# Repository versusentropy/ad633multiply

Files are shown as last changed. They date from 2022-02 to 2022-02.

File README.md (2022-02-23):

# eurorack AD633 mulitply

## v2 

minor bugfixes - should workk exactly like my manually fixed version - but I have not ordered these exact gerbers. Please report, if you do.

### 4 to 3 matrix mixer with gain 2

### 3 outputs to AD633 (X * Y) / 10 + Z

### output gain 0..1.5

### 2 DC coupled outputs
one with fixed gain

### 2 AC coupled outputs

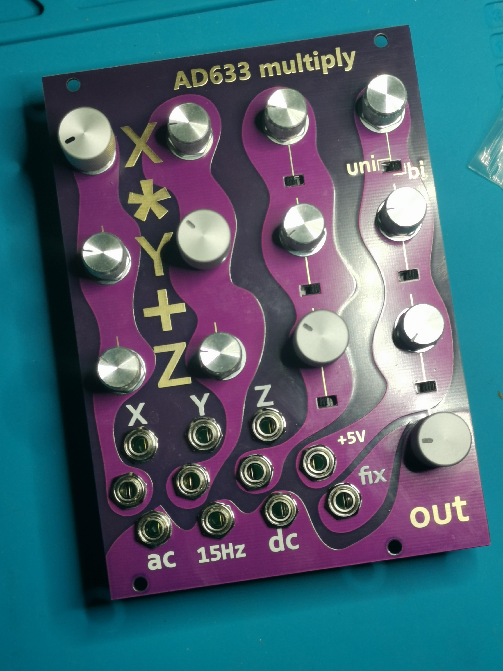
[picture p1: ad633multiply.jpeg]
pcb


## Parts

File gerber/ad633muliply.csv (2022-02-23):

Comment | Designator | Footprint | LCSC
22uF | C1,C2,C30 | Capacitor_SMD:C_0805_2012Metric | C45783
68pF | C13,C14,C15,C16,C17,C18,C21,C22,C23,C24,C26,C28 | Capacitor_SMD:C_0402_1005Metric | C14441
100n 50V X7R | C3,C4,C5,C6,C7,C8,C9,C10,C11,C12,C19,C20,C25,C29 | Capacitor_SMD:C_0402_1005Metric | C307331
LM4040C50FTA | D1 | Package_TO_SOT_SMD:SOT-23 | C202168
16V 150mA 0805 PTC Resettable Fuses ROHS | FB1,FB2 | Fuse:Fuse_0805_2012Metric | C30198
22k | R1,R76 | Resistor_SMD:R_0603_1608Metric | C126297
1k | R2,R5,R35,R36,R40,R42,R78,R79 | Resistor_SMD:R_0603_1608Metric | C21190
200k | R21,R22,R23,R33,R34,R43 | Resistor_SMD:R_0603_1608Metric | C319781
10k | R3 | Resistor_SMD:R_0402_1005Metric | C98838
36k5 | R4,R74 | Resistor_SMD:R_0603_1608Metric | C51261
100k | R6,R7,R8,R9,R10,R11,R12,R13,R14,R15,R16,R17,R18,R19,R20,R30,R31,R32,R37,R38,R39,R57,R59,R60,R63,R64 | Resistor_SMD:R_0402_1005Metric | C319963
TL074 | U1,U9,U10,U11 | Package_SO:TSSOP-14_4.4x5mm_P0.65mm | C96507
Xout | J1 | kicad_jacks:Jack_3.5mm_QingPu_WQP-PJ398SM_Vertical_CircularHolesSMALL
ac_15_out | J2 | kicad_jacks:Jack_3.5mm_QingPu_WQP-PJ398SM_Vertical_CircularHolesSMALL
Ain | J20 | kicad_jacks:Jack_3.5mm_QingPu_WQP-PJ398SM_Vertical_CircularHolesSMALL
Cin | J21 | kicad_jacks:Jack_3.5mm_QingPu_WQP-PJ398SM_Vertical_CircularHolesSMALL
ac_159_out | J22 | kicad_jacks:Jack_3.5mm_QingPu_WQP-PJ398SM_Vertical_CircularHolesSMALL
Yout | J3 | kicad_jacks:Jack_3.5mm_QingPu_WQP-PJ398SM_Vertical_CircularHolesSMALL
Din | J33 | kicad_jacks:Jack_3.5mm_QingPu_WQP-PJ398SM_Vertical_CircularHolesSMALL
out | J34 | kicad_jacks:Jack_3.5mm_QingPu_WQP-PJ398SM_Vertical_CircularHolesSMALL
outAtt | J37 | kicad_jacks:Jack_3.5mm_QingPu_WQP-PJ398SM_Vertical_CircularHolesSMALL
Bin | J38 | kicad_jacks:Jack_3.5mm_QingPu_WQP-PJ398SM_Vertical_CircularHolesSMALL
Zout | J4 | kicad_jacks:Jack_3.5mm_QingPu_WQP-PJ398SM_Vertical_CircularHolesSMALL
25kB to 100kB | RV6 | myKicadLib:RD901F-ALPHA-POT-T18
100kB | RV1,RV2,RV3,RV4,RV5,RV7,RV8,RV9,RV10,RV11,RV12,RV13 | myKicadLib:RD901F-ALPHA-POT-T18
AS1D-2M-10-Z | SW1,SW2,SW3,SW4,SW5,SW6 | myKicadLib:AS1D-2M-10-Z
AD633 | U12 | Package_DIP:DIP-8_W7.62mm_Socket
POWER | J6 | myKicadLib:eurorac_power
AC outs unity att | J5 | Connector_PinHeader_2.54mm:PinHeader_1x03_P2.54mm_Vertical
?k | R41 | Resistor_THT:R_Axial_DIN0207_L6.3mm_D2.5mm_P10.16mm_Horizontal | optional remove R@RC
?nF | C27 | Capacitor_THT:CP_Radial_D6.3mm_P2.50mm | optional remove C@RC

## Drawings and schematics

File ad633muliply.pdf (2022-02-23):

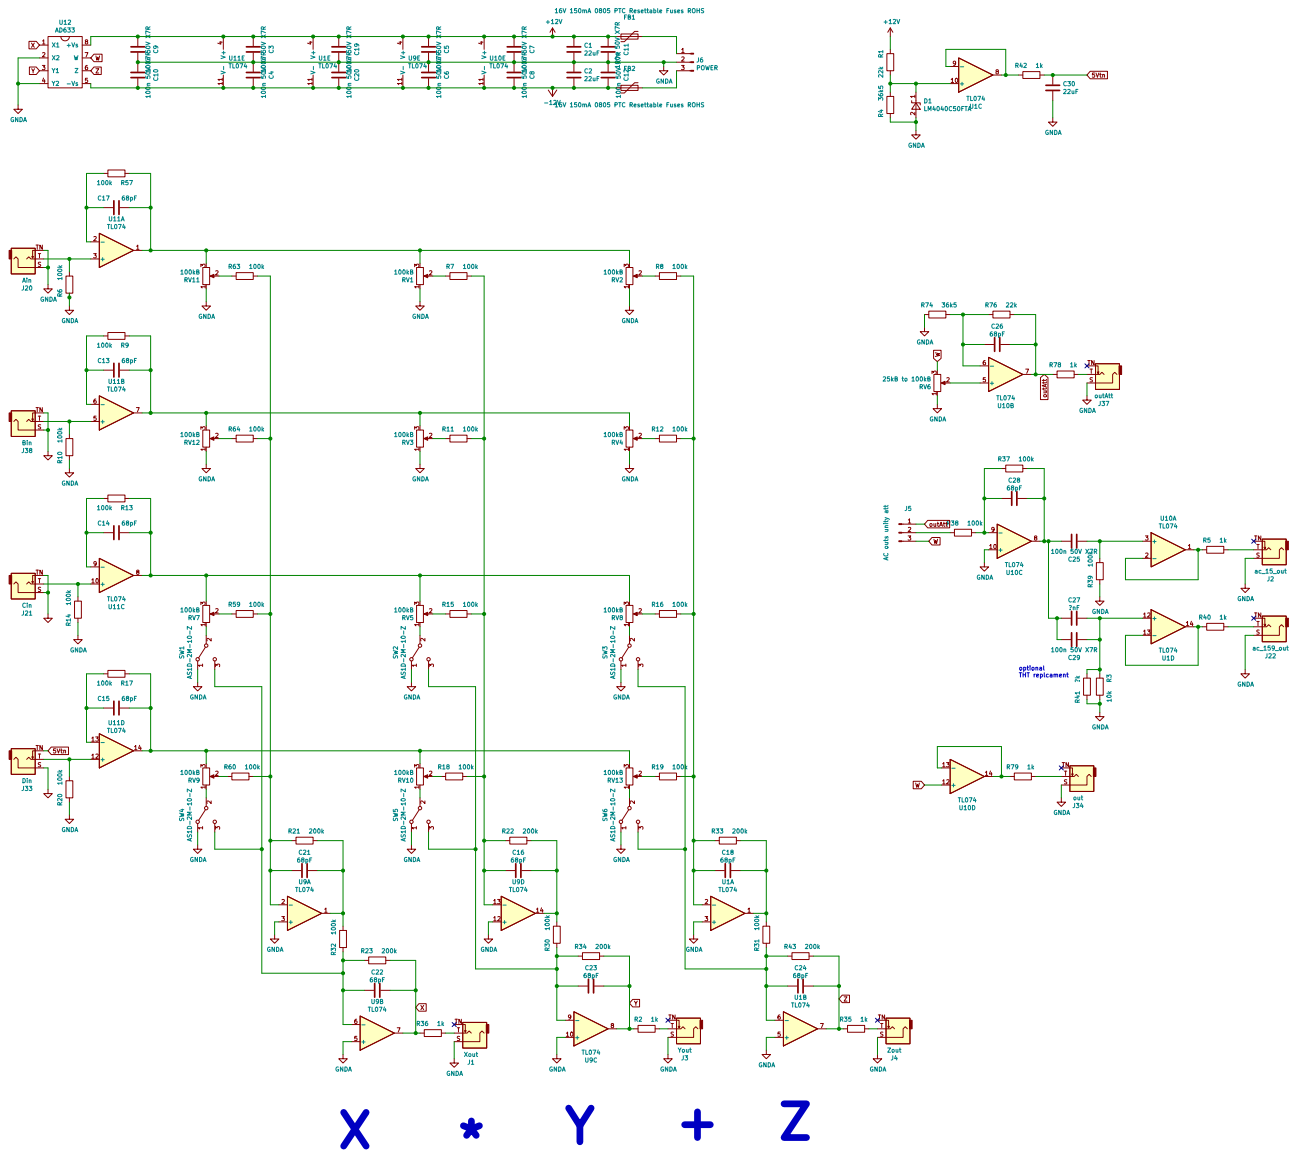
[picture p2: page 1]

16V 150mA 0805 PTC Resettable Fuses ROHS

16V 150mA 0805 PTC Resettable Fuses ROHS GNDA

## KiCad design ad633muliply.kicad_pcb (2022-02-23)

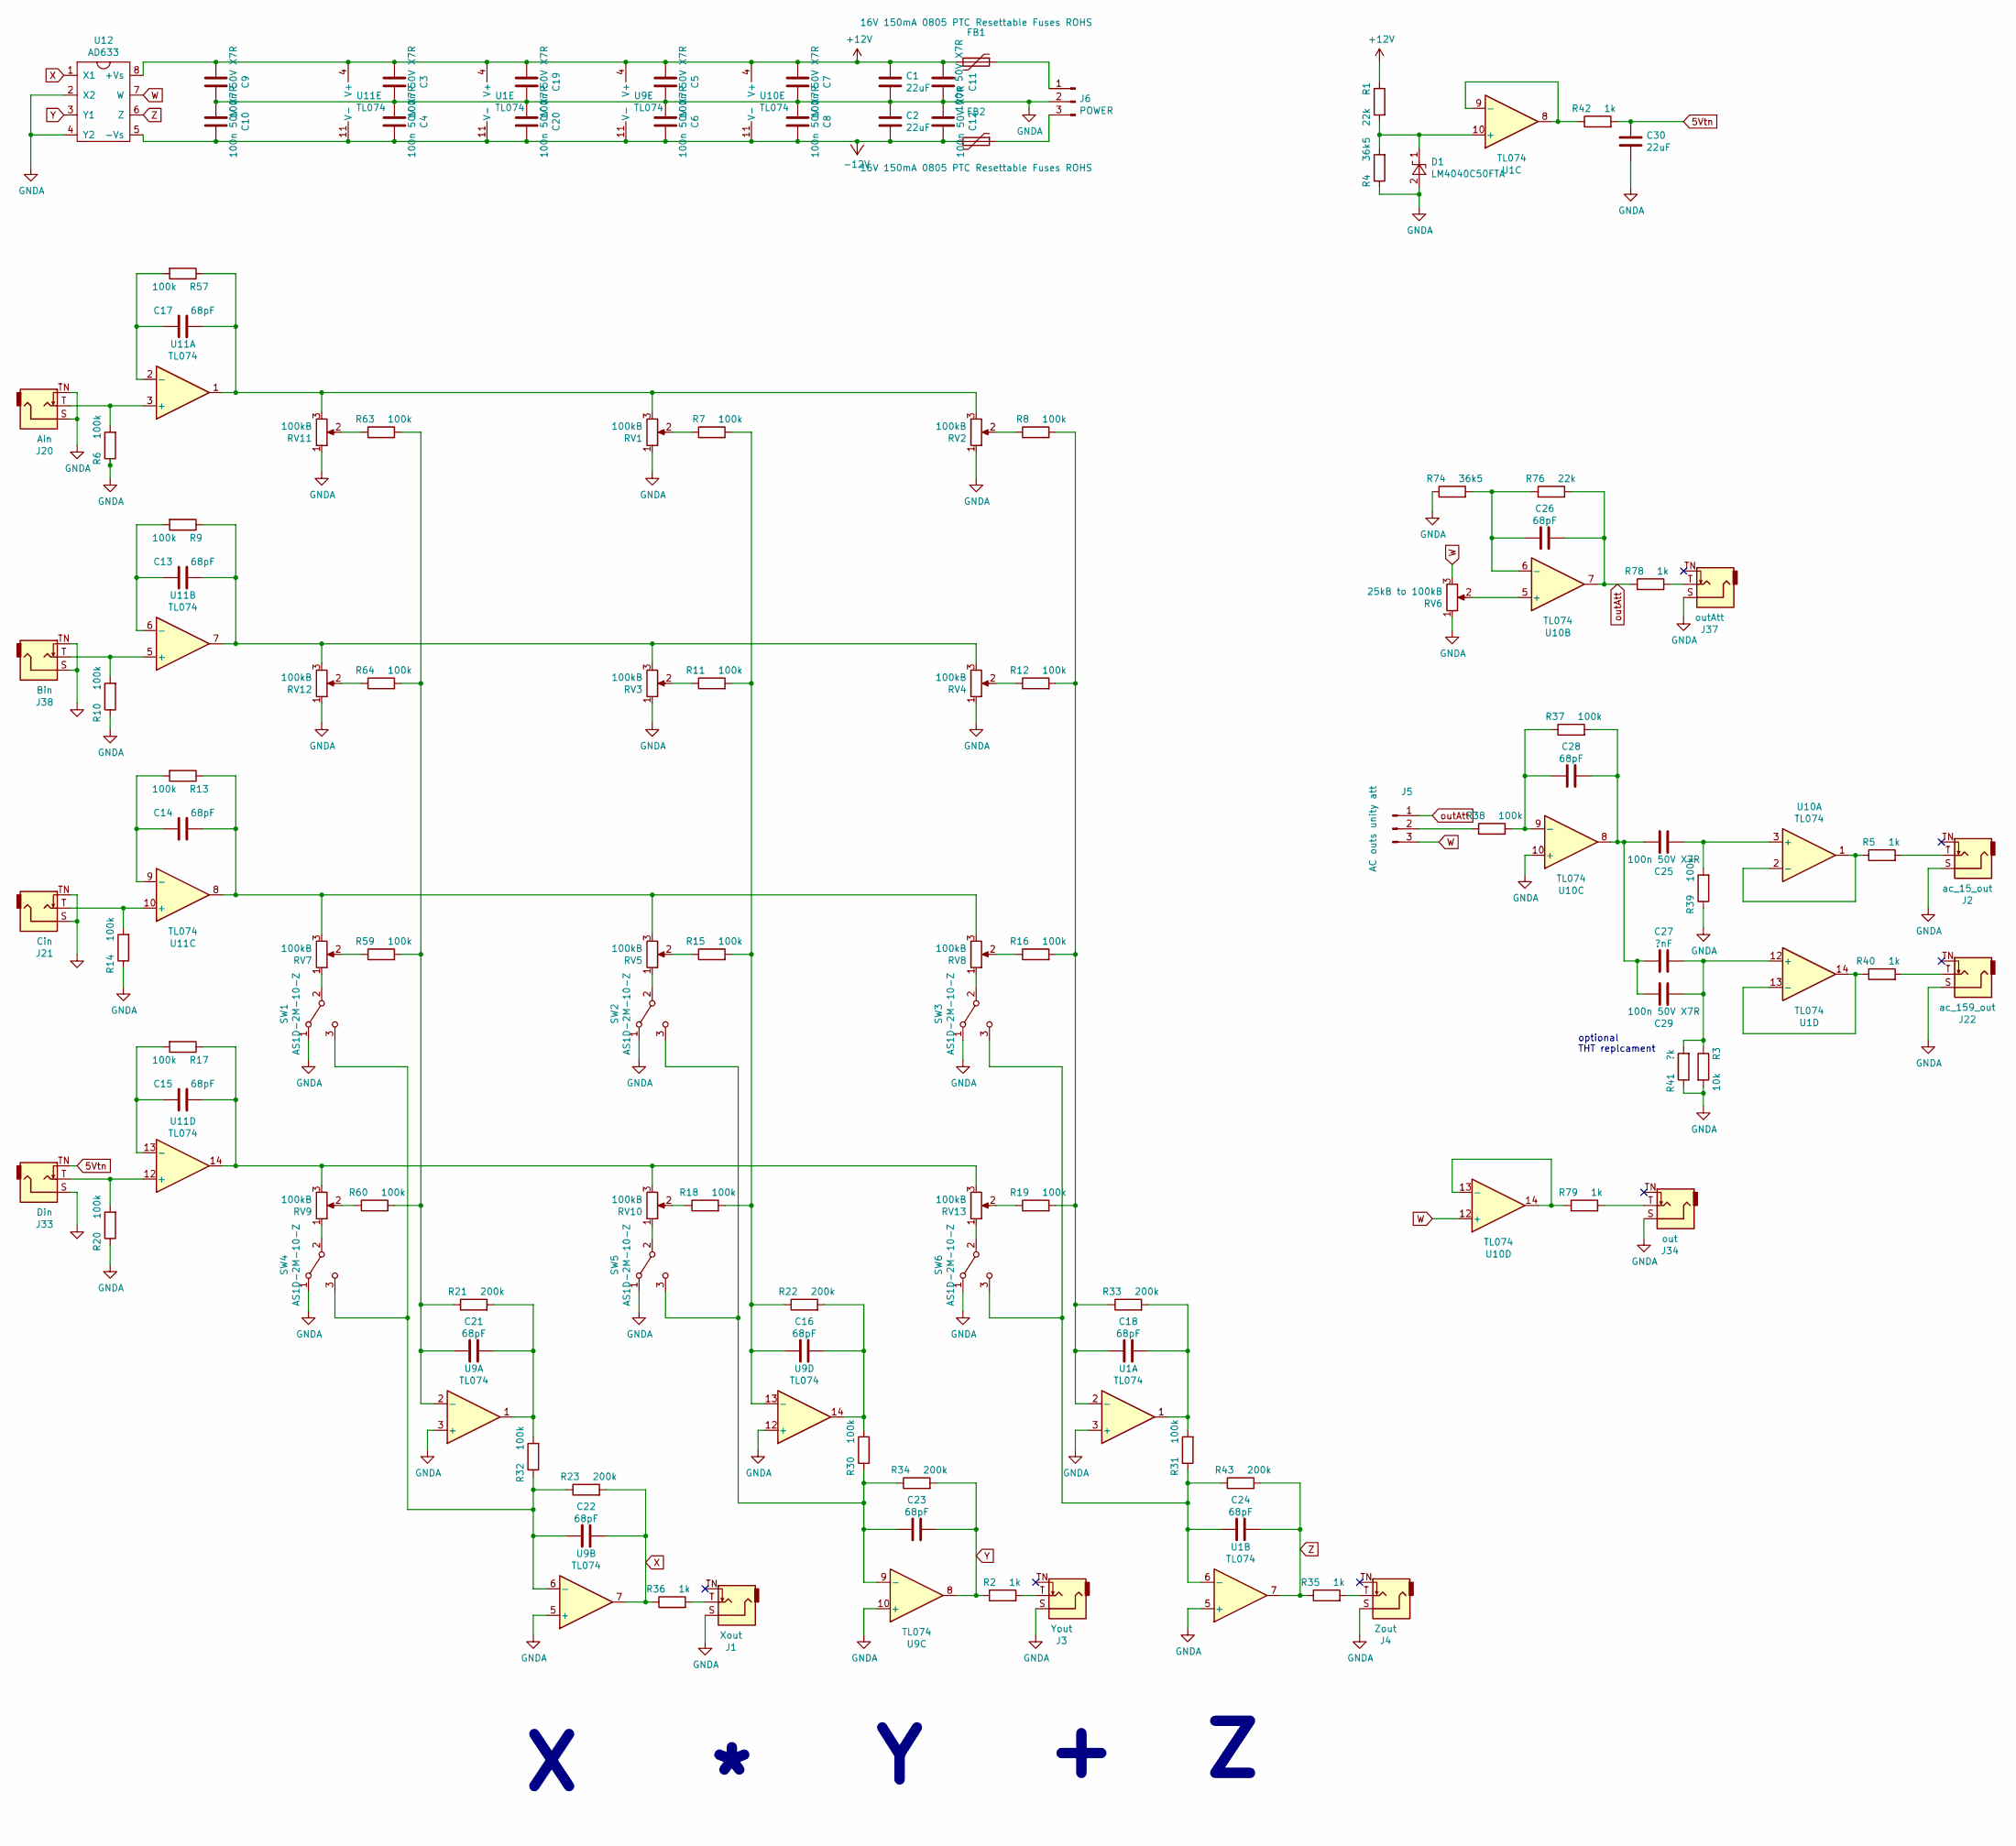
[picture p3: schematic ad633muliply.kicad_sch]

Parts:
C1, C2, C30: 22uF; C_0805_2012Metric; LCSC C45783
C3, C4, C5, C6, C7, C8, C9, C10, C11, C12, C19, C20, C25, C29: 100n 50V X7R; C_0402_1005Metric; LCSC C307331
C13, C14, C15, C16, C17, C18, C21, C22, C23, C24, C26, C28: 68pF; C_0402_1005Metric; LCSC C14441
C27: ?nF; CP_Radial_D6.3mm_P2.50mm
D1: LM4040C50FTA; SOT-23; LCSC C202168
FB1, FB2: 16V 150mA 0805 PTC Resettable Fuses ROHS; Fuse_0805_2012Metric; LCSC C30198
J1: Xout; Jack_3.5mm_QingPu_WQP-PJ398SM_Vertical_CircularHolesSMALL
J2: ac_15_out; Jack_3.5mm_QingPu_WQP-PJ398SM_Vertical_CircularHolesSMALL
J3: Yout; Jack_3.5mm_QingPu_WQP-PJ398SM_Vertical_CircularHolesSMALL
J4: Zout; Jack_3.5mm_QingPu_WQP-PJ398SM_Vertical_CircularHolesSMALL
J5: AC outs unity att; PinHeader_1x03_P2.54mm_Vertical
J6: POWER; eurorac_power
J20: Ain; Jack_3.5mm_QingPu_WQP-PJ398SM_Vertical_CircularHolesSMALL
J21: Cin; Jack_3.5mm_QingPu_WQP-PJ398SM_Vertical_CircularHolesSMALL
J22: ac_159_out; Jack_3.5mm_QingPu_WQP-PJ398SM_Vertical_CircularHolesSMALL
J33: Din; Jack_3.5mm_QingPu_WQP-PJ398SM_Vertical_CircularHolesSMALL
J34: out; Jack_3.5mm_QingPu_WQP-PJ398SM_Vertical_CircularHolesSMALL
J37: outAtt; Jack_3.5mm_QingPu_WQP-PJ398SM_Vertical_CircularHolesSMALL
J38: Bin; Jack_3.5mm_QingPu_WQP-PJ398SM_Vertical_CircularHolesSMALL
R1, R76: 22k; R_0603_1608Metric; LCSC C126297
R2, R5, R35, R36, R40, R42, R78, R79: 1k; R_0603_1608Metric; LCSC C21190
R3: 10k; R_0402_1005Metric; LCSC C98838
R4, R74: 36k5; R_0603_1608Metric; LCSC C51261
R6, R7, R8, R9, R10, R11, R12, R13, R14, R15, R16, R17, R18, R19, R20, R30, R31, R32, R37, R38, R39, R57, R59, R60, R63, R64: 100k; R_0402_1005Metric; LCSC C319963
R21, R22, R23, R33, R34, R43: 200k; R_0603_1608Metric; LCSC C319781
R41: ?k; R_Axial_DIN0207_L6.3mm_D2.5mm_P10.16mm_Horizontal
RV1, RV2, RV3, RV4, RV5, RV7, RV8, RV9, RV10, RV11, RV12, RV13: 100kB; RD901F-ALPHA-POT-T18
RV6: 25kB to 100kB; RD901F-ALPHA-POT-T18
SW1, SW2, SW3, SW4, SW5, SW6: AS1D-2M-10-Z; Mouser 229-AS1D-2M-10-Z
U1, U9, U10, U11: TL074; TSSOP-14_4.4x5mm_P0.65mm; LCSC C96507
U12: AD633; DIP-8_W7.62mm_Socket; Mouser 584-AD633ANZ

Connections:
5Vtn: C30.1, J33.TN, R42.2
+12V: C1.1, C3.2, C5.2, C7.2, C9.2, C11.2, C19.2, FB1.2, R1.1, U1.4 (V+), U9.4 (V+), U10.4 (V+), U11.4 (V+), U12.8 (+Vs)
-12V: C2.2, C4.1, C6.1, C8.1, C10.1, C12.1, C20.1, FB2.2, U1.11 (V-), U9.11 (V-), U10.11 (V-), U11.11 (V-), U12.5 (-Vs)
GNDA: C1.2, C2.1, C3.1, C4.2, C5.1, C6.2, C7.1, C8.2, C9.1, C10.2, C11.1, C12.2, C19.1, C20.2, C30.2, D1.2 (A), J1.S, J2.S, J3.S, J4.S, J6.2, J20.S, J20.TN, J21.S, J21.TN, J22.S, J33.S, J34.S, J37.S, J38.S, J38.TN, R3.2, R4.1, R6.1, R10.1, R14.1, R20.1, R39.1, R41.1, R74.1, RV1.1, RV2.1, RV3.1, RV4.1, RV6.1, RV11.1, RV12.1, SW1.1 (A), SW2.1 (A), SW3.1 (A), SW4.1 (A), SW5.1 (A), SW6.1 (A), U1.3 (+), U1.5 (+), U9.3 (+), U9.5 (+), U9.10 (+), U9.12 (+), U10.10 (+), U12.2 (X2), U12.4 (Y2)
unnamed: C13.1, R9.1, RV3.3, RV4.3, RV12.3, U11.7
unnamed: C13.2, R9.2, U11.6 (-)
unnamed: C14.1, R13.1, RV5.3, RV7.3, RV8.3, U11.8
unnamed: C14.2, R13.2, U11.9 (-)
unnamed: C15.1, R17.1, RV9.3, RV10.3, RV13.3, U11.14
unnamed: C15.2, R17.2, U11.13 (-)
unnamed: C16.1, R22.2, R30.2, U9.14
unnamed: C16.2, R7.2, R11.2, R15.2, R18.2, R22.1, U9.13 (-)
unnamed: C17.1, R57.1, RV1.3, RV2.3, RV11.3, U11.1
unnamed: C17.2, R57.2, U11.2 (-)
unnamed: C18.1, R31.2, R33.2, U1.1
unnamed: C18.2, R8.2, R12.2, R16.2, R19.2, R33.1, U1.2 (-)
unnamed: C21.1, R21.2, R32.2, U9.1
unnamed: C21.2, R21.1, R59.2, R60.2, R63.2, R64.2, U9.2 (-)
unnamed: C23.2, R30.1, R34.1, SW2.3 (C), SW5.3 (C), U9.9 (-)
unnamed: C25.1, C27.2, C28.1, C29.1, R37.2, U10.8
unnamed: C25.2, R39.2, U10.3 (+)
unnamed: C26.2, R74.2, R76.1, U10.6 (-)
unnamed: C27.1, C29.2, R3.1, R41.2, U1.12 (+)
unnamed: C28.2, R37.1, R38.2, U10.9 (-)
unnamed: D1.1 (K), R1.2, R4.2, U1.10 (+)
unnamed: FB1.1, J6.1
unnamed: FB2.1, J6.3
unnamed: J1.T, R36.2
unnamed: J2.T, R5.2
unnamed: J3.T, R2.2
unnamed: J4.T, R35.2
unnamed: J5.2, R38.1
unnamed: J20.T, R6.2, U11.3 (+)
unnamed: J21.T, R14.2, U11.10 (+)
unnamed: J22.T, R40.2
unnamed: J33.T, R20.2, U11.12 (+)
unnamed: J34.T, R79.2
unnamed: J37.T, R78.2
unnamed: J38.T, R10.2, U11.5 (+)
unnamed: R5.1, U10.1, U10.2 (-)
unnamed: R7.1, RV1.2
unnamed: R8.1, RV2.2
unnamed: R11.1, RV3.2
unnamed: R12.1, RV4.2
unnamed: R15.1, RV5.2
unnamed: R16.1, RV8.2
unnamed: R18.1, RV10.2
unnamed: R19.1, RV13.2
unnamed: R40.1, U1.13 (-), U1.14
unnamed: R42.1, U1.8, U1.9 (-)
unnamed: R59.1, RV7.2
unnamed: R60.1, RV9.2
unnamed: R63.1, RV11.2
unnamed: R64.1, RV12.2
unnamed: R79.1, U10.13 (-), U10.14
unnamed: RV5.1, SW2.2 (B)
unnamed: RV7.1, SW1.2 (B)
unnamed: RV8.1, SW3.2 (B)
unnamed: RV9.1, SW4.2 (B)
unnamed: RV10.1, SW5.2 (B)
unnamed: RV13.1, SW6.2 (B)
unnamed: C22.2, R23.1, R32.1, SW1.3 (C), SW4.3 (C), U9.6 (-)
unnamed: C24.2, R31.1, R43.1, SW3.3 (C), SW6.3 (C), U1.6 (-)
unnamed: RV6.2, U10.5 (+)
W: J5.3, RV6.3, U10.12 (+), U12.7 (W)
X: C22.1, R23.2, R36.1, U9.7, U12.1 (X1)
Y: C23.1, R2.1, R34.2, U9.8, U12.3 (Y1)
Z: C24.1, R35.1, R43.2, U1.7, U12.6 (Z)
outAtt: C26.1, J5.1, R76.2, R78.1, U10.7

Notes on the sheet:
optional THT replcament

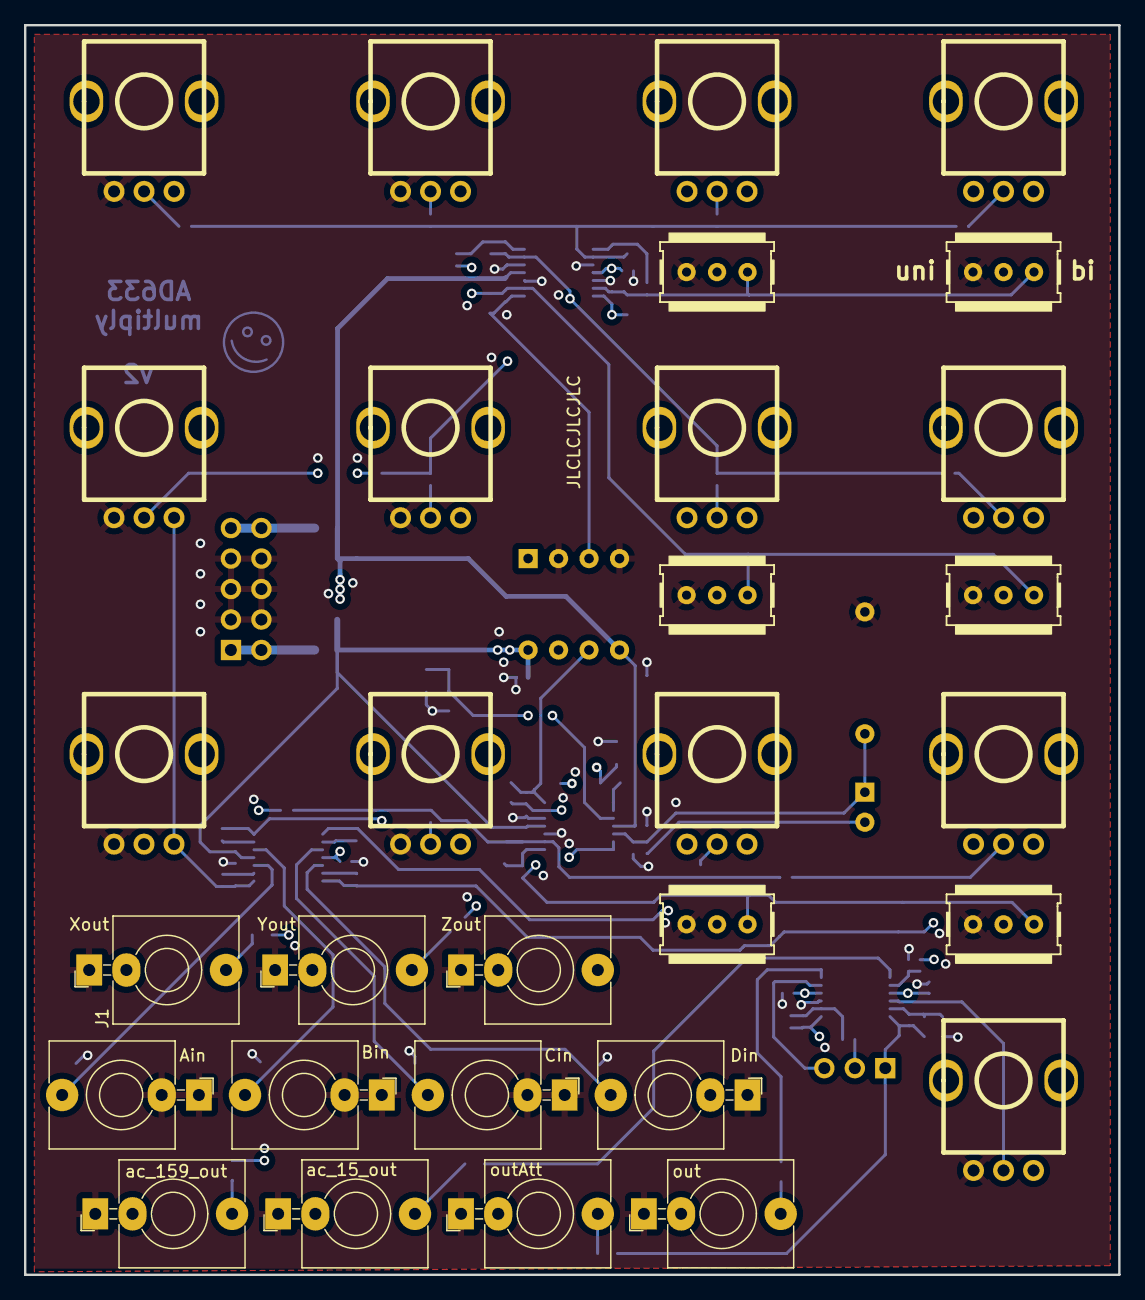
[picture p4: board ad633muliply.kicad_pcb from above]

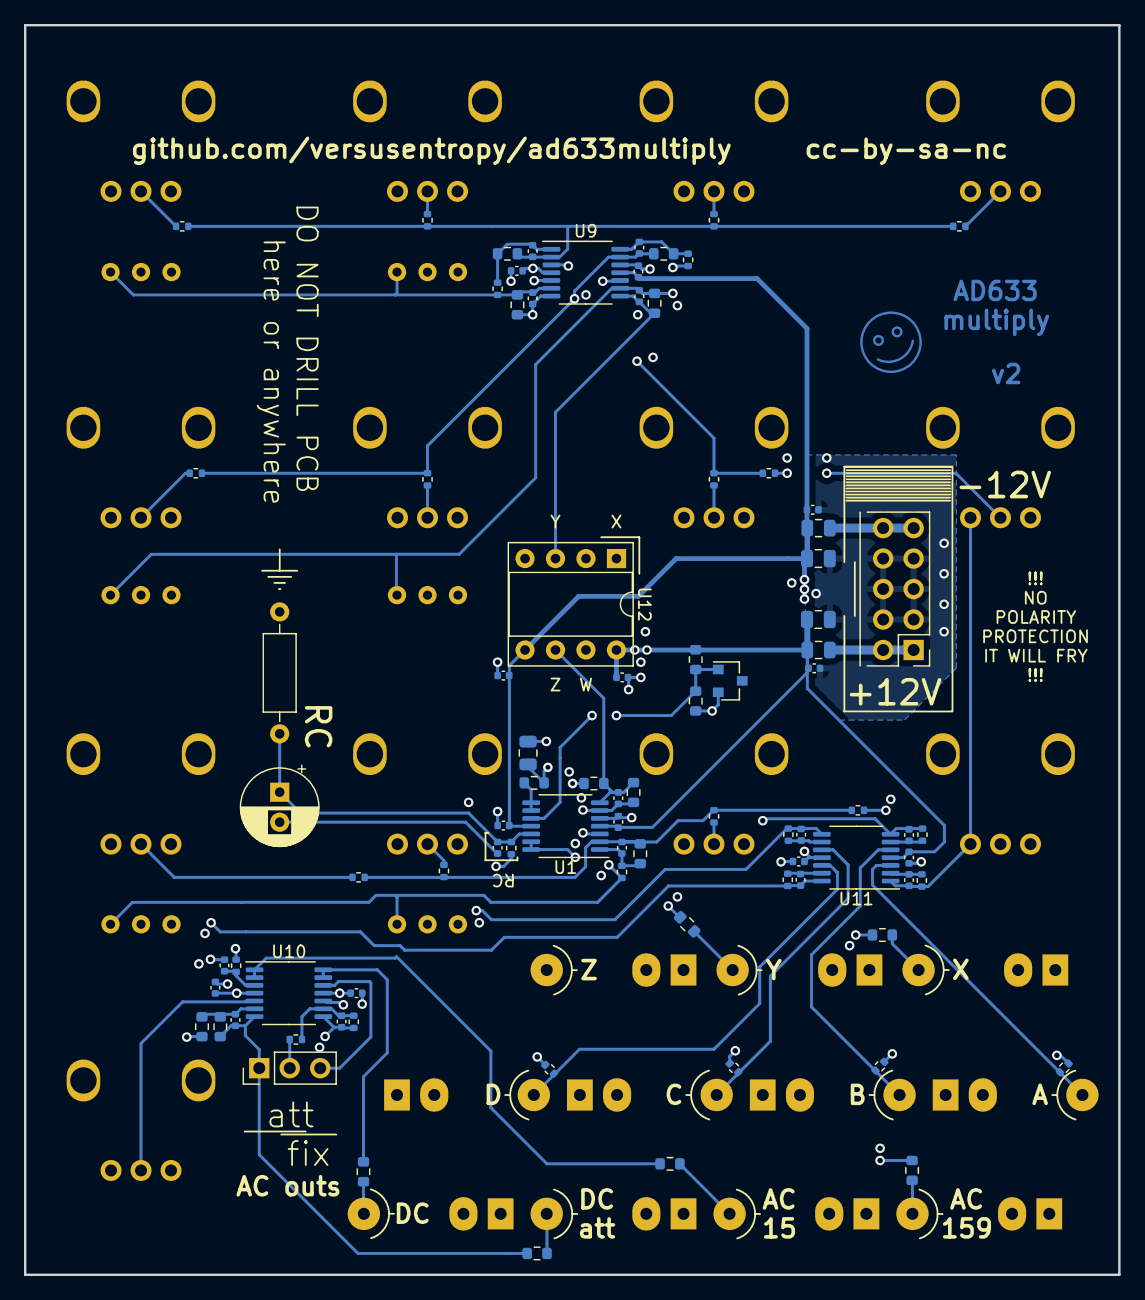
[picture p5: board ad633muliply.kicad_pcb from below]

Board: 4 copper layers, 91.2 x 104.1 mm, 116 parts (86 on the bottom side), 69 nets.

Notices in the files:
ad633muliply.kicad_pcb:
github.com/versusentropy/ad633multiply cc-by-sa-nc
